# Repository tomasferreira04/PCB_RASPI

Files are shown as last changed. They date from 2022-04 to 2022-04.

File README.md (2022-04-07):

# PCB_RASPI
MPPT solar charger controller with a DC/DC boost controller for Raspberry Pi and GSM with Peripheral outputs for GPIO
Design on Autodesk EAGLE.

This PCB is a power management controller for Solar pannels and Li-po batteries.
As 2 40pin GPIO headers for raspberry pi and gsm connection
As 5 I/O for fans, leds, buttons and sensors.
1 USB-A output for 5V/1A to provide power for Raspberry Pi.

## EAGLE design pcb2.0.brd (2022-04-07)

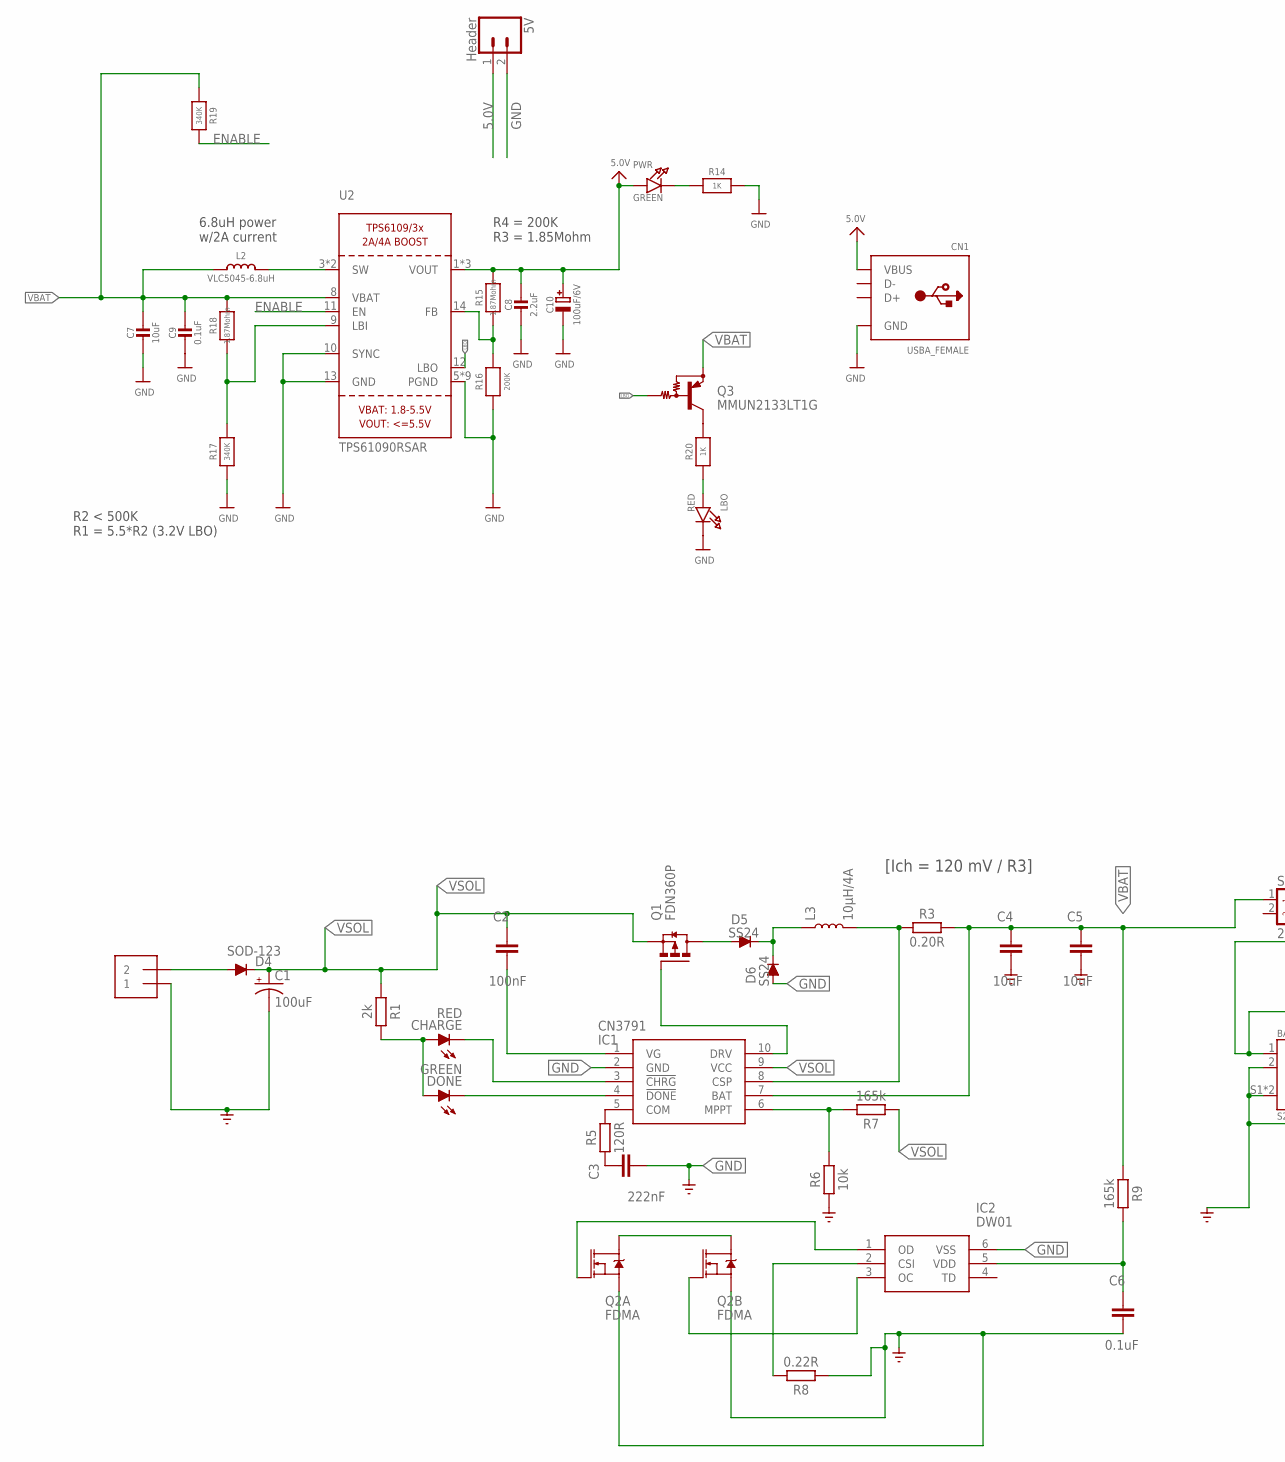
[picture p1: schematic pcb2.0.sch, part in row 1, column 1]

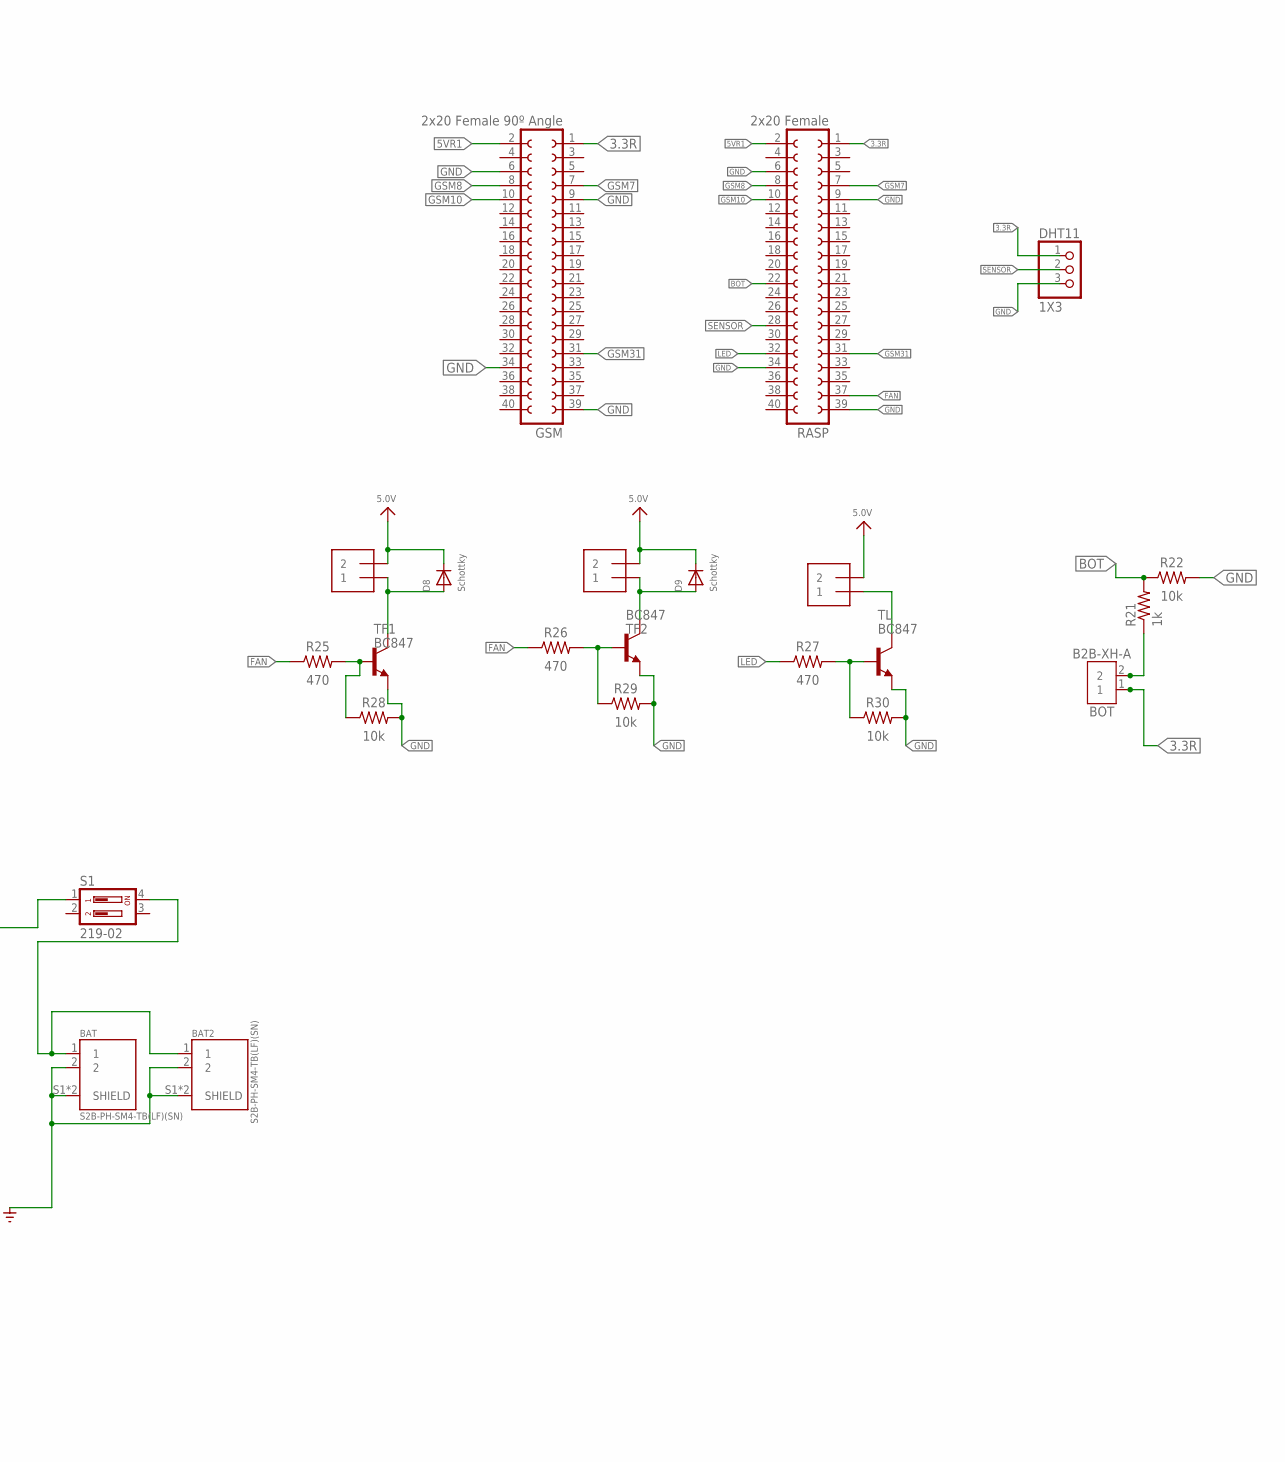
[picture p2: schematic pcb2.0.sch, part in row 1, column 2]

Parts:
5V: Header; 1X02
BAT, BAT2: S2B-PH-SM4-TB(LF)(SN)
BOT: B2B-XH-A
C1: 100uF; 153CLV-0505
C2: 100nF; CAP_0603
C3: 222nF; CAP_0603
C4, C5: 10uF; CAP_0603
C6: 0.1uF; CAP_0603
C7: 10uF; 0805-NO
C8: 2.2uF; 0805-NO
C9: 0.1uF; 0805-NO
C10: 100uF/6V; EIA3528-21/B-R
CHARGE: RED; LED_CHIP-LED0603MP
CN1: USBA_FEMALE; USB_HOST-PTH
D4: SOD-123; DIODE_SOD123
D5, D6: SS24; DIODE_SOD123
D8, D9: Schottky; SOD-123
DHT11: 1X3; 1X03
DONE: GREEN; LED_CHIP-LED0603MP
FAN1, FAN2: 1X2-3.5MM
GSM: 2x20 Female 90º Angle; FE20-2W
IC1: CN3791; SOP100P600X175-10N
IC2: DW01; SOT95P280X135-6N
L2: VLC5045-6.8uH; INDUCTOR_5X5MM_TDK_VLC5045
L3: 10µH/4A; CR54
LBO: RED; CHIPLED_0805_NOOUTLINE
LED: 1X2-3.5MM
PWR: GREEN; CHIPLED_0805_NOOUTLINE
Q1: FDN360P; SUPER-SOT3
Q2: FDMA; MICROFET_2X2
Q3: MMUN2133LT1G; SC59-BEC
R1: 2k; RESC1608X60
R3: 0.20R; RESC1608X60
R5: 120R; RESC1608X60
R6: 10k; RESC1608X60
R7, R9: 165k; RESC1608X60
R8: 0.22R; RESC1608X60
R14, R20: 1K; 0805-NO
R15, R18: 1.87Mohm; 0805-NO
R16: 200K; 0805-NO
R17, R19: 340K; 0805-NO
R21: 1k; R0805
R22, R28, R29, R30: 10k; RESC2012X65
R25, R26, R27: 470; RESC2012X65
RASP: 2x20 Female; FE20-2
S1: 219-02; CTS-219-02
TF1, TF2: BC847; SOT23
TL: BC847; SOT23
U2: TPS61090RSAR; PVQFN-16
VIN: 1X2-3.5MM

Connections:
3.3R: BOT.1, DHT11.1, GSM.1, RASP.1
5.0V: 5V.1, C8.1, C10.+, CN1.VBUS, D8.C, D9.C, FAN1.2, FAN2.2, LED.2, PWR.A, R15.2, U2.1 (VOUT), U2.15 (VOUT), U2.16 (VOUT)
5VR1: GSM.2, RASP.2
BOT: R21.2, R22.1, RASP.22
ENABLE: R19.2, U2.11 (EN)
FAN: R25.1, R26.1, RASP.37
GND: 5V.2, BAT.2, BAT.S1 (SHIELD), BAT.S2 (SHIELD), BAT2.2, BAT2.S1 (SHIELD), BAT2.S2 (SHIELD), C1.-, C3.2, C4.2, C5.2, C6.2, C7.2, C8.2, C9.2, C10.-, CN1.GND, D6.A, DHT11.3, GSM.6, GSM.9, GSM.34, GSM.39, IC1.2 (GND), IC2.6 (VSS), LBO.C, Q2.S1 (S), Q2.S2 (S), R6.1, R8.1, R14.2, R16.1, R17.1, R22.2, R28.2, R29.2, R30.2, RASP.6, RASP.9, RASP.34, RASP.39, TF1.2 (E), TF2.2 (E), TL.2 (E), U2.5 (PGND), U2.6 (PGND), U2.7 (PGND), U2.10 (SYNC), U2.13 (GND), U2.P$18 (PGND), U2.P$19 (PGND), U2.P$20 (PGND), U2.P$21 (PGND), U2.P$22 (PGND), U2.THERMAL (PGND), VIN.1
GSM7: GSM.7, RASP.7
GSM8: GSM.8, RASP.8
GSM10: GSM.10, RASP.10
GSM31: GSM.31, RASP.31
LBO: Q3.B, U2.12 (LBO)
LED: R27.1, RASP.32
unnamed: L2.P$2 (2), U2.3 (SW), U2.4 (SW)
unnamed: C2.2, IC1.1 (VG)
unnamed: CHARGE.C, IC1.3 (!CHRG)
unnamed: IC1.8 (CSP), L3.P$2 (2), R3.1
unnamed: CHARGE.A, DONE.A, R1.2
unnamed: DONE.C, IC1.4 (!DONE)
unnamed: IC1.5 (COM), R5.2
unnamed: C3.1, R5.1
unnamed: IC1.10 (DRV), Q1.1 (G)
unnamed: R17.2, R18.1, U2.9 (LBI)
unnamed: D5.A, Q1.3 (D)
unnamed: D5.C, D6.C, L3.P$1 (1)
unnamed: IC1.6 (MPPT), R6.2, R7.2
unnamed: Q2.D1 (D), Q2.D1_2 (D), Q2.D2 (D), Q2.D2_2 (D)
unnamed: BAT.1, BAT2.1, S1.4
unnamed: IC2.1 (OD), Q2.G1 (G)
unnamed: IC2.3 (OC), Q2.G2 (G)
unnamed: C6.1, IC2.5 (VDD), R9.2
unnamed: IC2.2 (CSI), R8.2
unnamed: BOT.2, R21.1
unnamed: PWR.C, R14.1
unnamed: LBO.A, R20.1
unnamed: Q3.C, R20.2
unnamed: R15.1, R16.2, U2.14 (FB)
unnamed: R25.2, R28.1, TF1.1 (B)
unnamed: R26.2, R29.1, TF2.1 (B)
unnamed: R27.2, R30.1, TL.1 (B)
unnamed: D8.A, FAN1.1, TF1.3 (C)
unnamed: D9.A, FAN2.1, TF2.3 (C)
unnamed: LED.1, TL.3 (C)
SENSOR: DHT11.2, RASP.28
VBAT: C4.1, C5.1, C7.1, C9.1, IC1.7 (BAT), L2.P$1 (1), Q3.E, R3.2, R9.1, R18.2, R19.1, S1.1, U2.8 (VBAT)
VSOL: C1.+, C2.1, D4.C, IC1.9 (VCC), Q1.2 (S), R1.1, R7.1
VSOLAR: D4.A, VIN.2

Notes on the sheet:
6.8uH power w/2A current
R2 < 500K R1 = 5.5*R2 (3.2V LBO)
R4 = 200K R3 = 1.85Mohm
[Ich = 120 mV / R3]

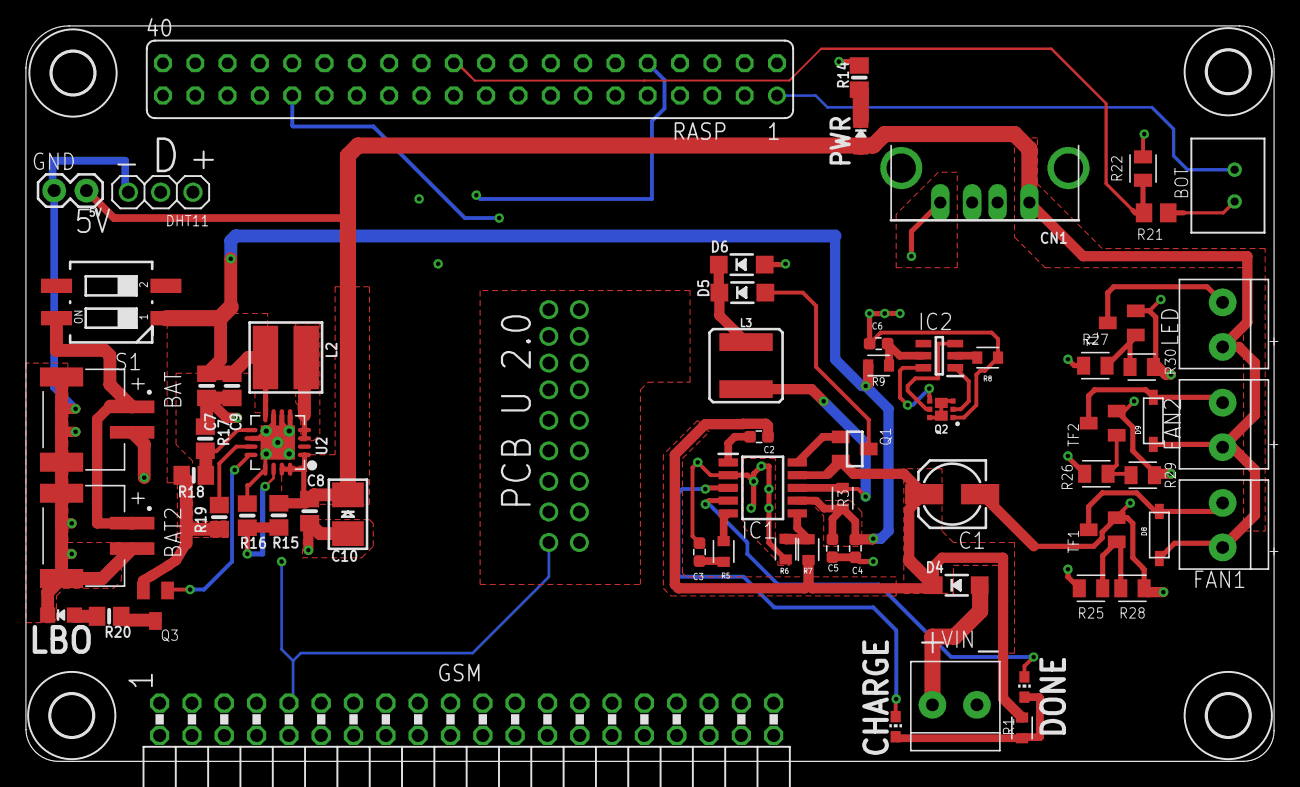
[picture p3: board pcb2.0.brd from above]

Board: 4 copper layers, 98.1 x 57.8 mm, 69 parts (0 on the bottom side), 47 nets.

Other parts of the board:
U$5, U$9, U$10, U$11: 3,3

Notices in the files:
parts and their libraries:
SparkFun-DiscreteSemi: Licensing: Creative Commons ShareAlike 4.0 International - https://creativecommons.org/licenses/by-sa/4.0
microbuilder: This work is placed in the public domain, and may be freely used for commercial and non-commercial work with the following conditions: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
